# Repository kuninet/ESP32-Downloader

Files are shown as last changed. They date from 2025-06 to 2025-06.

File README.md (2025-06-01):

# ESP32/ESP8266 Downloader基板

## 概要
* ESP32/ESP8266 Downloader基板です。
* ピン配置は ESP32 Downloader kitに合わせています。
* MOS FET x2個で自動書き込み回路を装備してしています。
* USBシリアルICはCH340Kを使用しています。

## 回路図
[回路図](image/ESP32-Downloder.pdf)

## イメージ
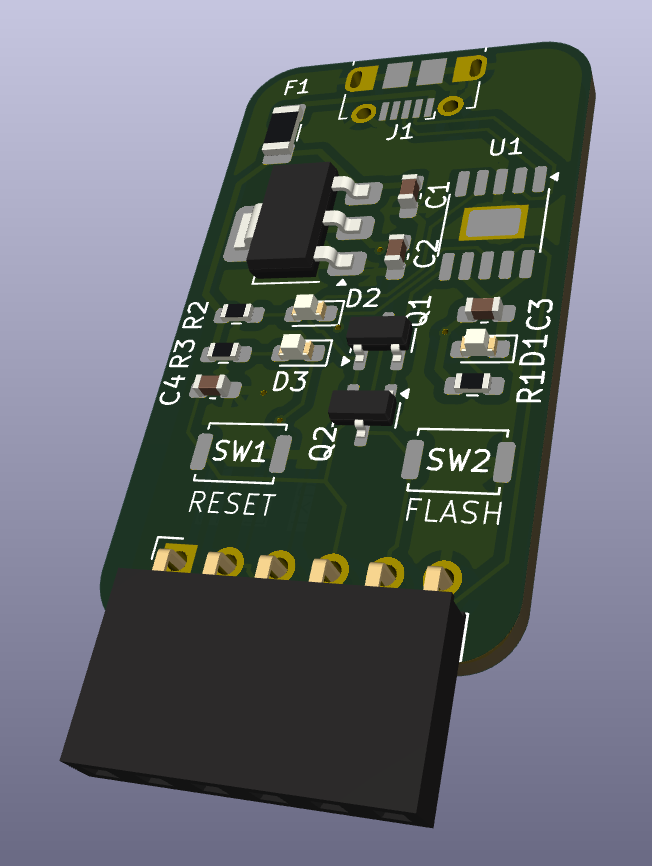
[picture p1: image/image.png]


## 参考
* ESP32 Downloader kit
  * https://docs.m5stack.com/ja/accessory/esp32_downloader_kit

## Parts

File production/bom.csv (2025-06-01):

Designator | Footprint | Quantity | Value | LCSC Part #
C1, C2 | 0603 | 2 | 22u
C3 | 0603 | 1 | 1u
C4 | 0603 | 1 | 0.1u
D1 | 0603 | 1 | LED_POWER
D2 | 0603 | 1 | LED_TXT
D3 | 0603 | 1 | LED_RXD
F1 | 1206 | 1 | Polyfuse
J1 | USB_Micro-B_Molex-105017-0001 | 1 | USB_B_Micro
J2 | PinSocket_1x06_P2.54mm_Horizontal | 1 | ESP32_DOWNLOAD_CON
Q1, Q2 | SOT-23 | 2 | BSS138
R1, R2, R3 | 0603 | 3 | 1k
SW1 | SW_Push_SPST_NO_Alps_SKRK | 1 | RESET
SW2 | SW_Push_SPST_NO_Alps_SKRK | 1 | FLASH
U1 | SSOP-10-1EP_3.9x4.9mm_P1mm_EP2.1x3.3mm | 1 | CH340K
U2 | SOT-223-3_TabPin2 | 1 | AMS1117-3.3

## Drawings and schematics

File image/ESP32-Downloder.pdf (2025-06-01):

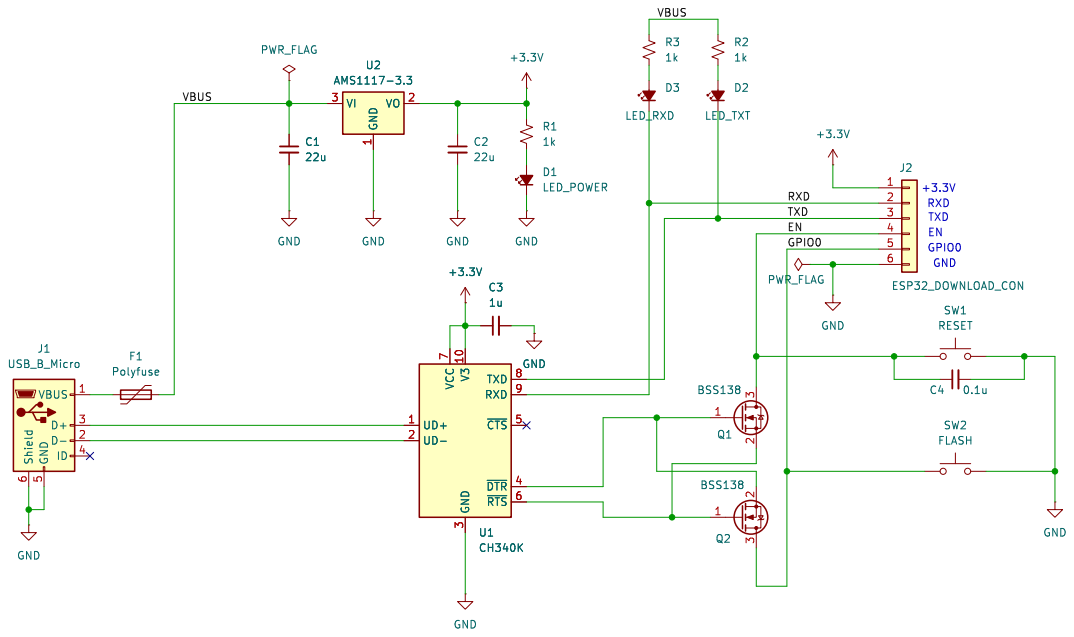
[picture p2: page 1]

3 TXD 8 RXD 9 ~{CTS}5 ~{DTR}4 ~{RTS}6 U1 CH340K C4 0.1u GND GND

3 TXD 8 RXD 9 ~{CTS}5 ~{DTR}4 ~{RTS}6 +3.3V GND

File: ESP32-Downloder.kicad_sch Sheet: / KUNI-NET

Id: 1/1 Title: ESP32 Downloader Board

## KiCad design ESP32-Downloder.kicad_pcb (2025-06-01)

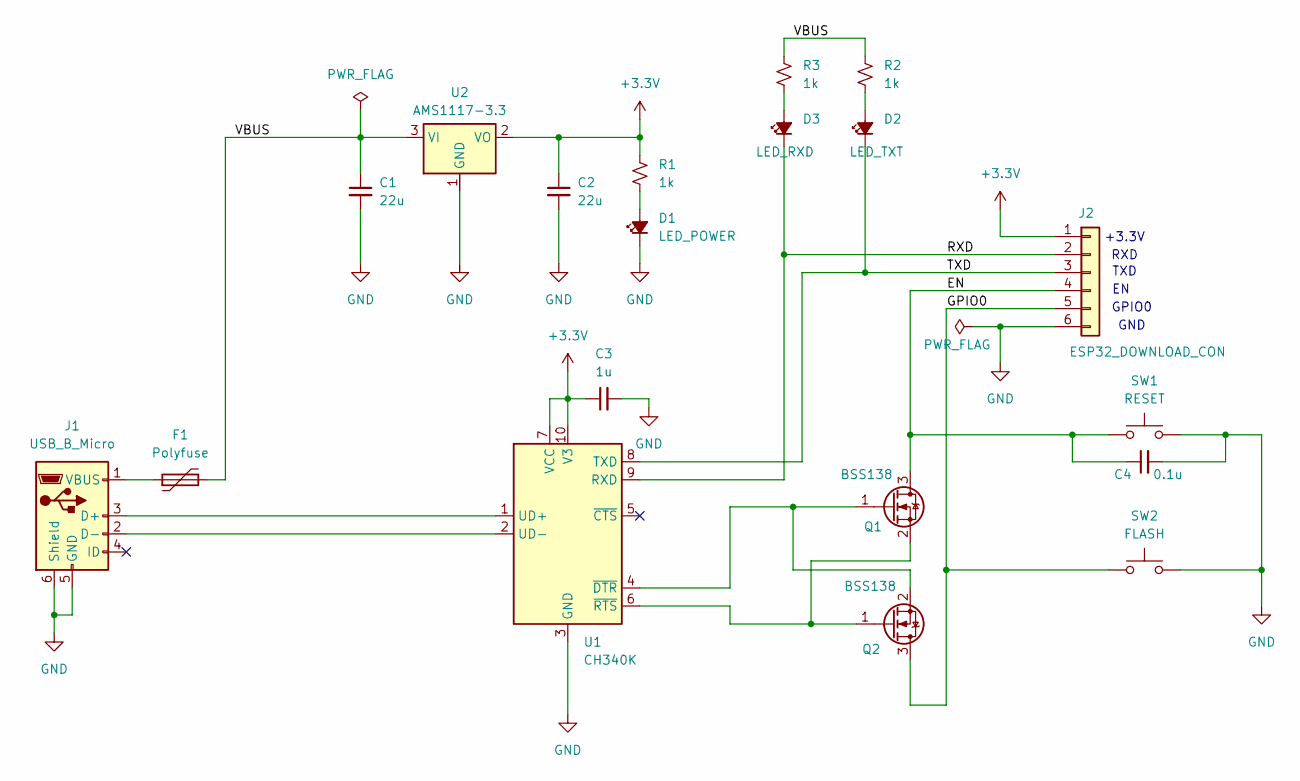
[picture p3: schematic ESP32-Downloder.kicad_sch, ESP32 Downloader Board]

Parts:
C1, C2: 22u; C_0603_1608Metric_Pad1.08x0.95mm_HandSolder
C3: 1u; C_0603_1608Metric_Pad1.08x0.95mm_HandSolder
C4: 0.1u; C_0603_1608Metric_Pad1.08x0.95mm_HandSolder
D1: LED_POWER; LED_0603_1608Metric_Pad1.05x0.95mm_HandSolder
D2: LED_TXT; LED_0603_1608Metric_Pad1.05x0.95mm_HandSolder
D3: LED_RXD; LED_0603_1608Metric_Pad1.05x0.95mm_HandSolder
F1: Polyfuse; Fuse_1206_3216Metric_Pad1.42x1.75mm_HandSolder
J1: USB_B_Micro; USB_Micro-B_Molex-105017-0001
J2: ESP32_DOWNLOAD_CON; PinSocket_1x06_P2.54mm_Horizontal
Q1, Q2: BSS138; SOT-23
R1, R2, R3: 1k; R_0603_1608Metric_Pad0.98x0.95mm_HandSolder
SW1: RESET; SW_Push_SPST_NO_Alps_SKRK
SW2: FLASH; SW_Push_SPST_NO_Alps_SKRK
U1: CH340K; SSOP-10-1EP_3.9x4.9mm_P1mm_EP2.1x3.3mm
U2: AMS1117-3.3; SOT-223-3_TabPin2

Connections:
+3.3V: C2.1, C3.1, J2.1, R1.1, U1.7 (VCC), U1.10 (V3), U2.2 (VO)
/EN: C4.1, J2.4, Q1.3 (D), SW1.1
/GPIO0: J2.5, Q2.3 (D), SW2.1
/RXD: D3.1 (K), J2.2, U1.9 (RXD)
/TXD: D2.1 (K), J2.3, U1.8 (TXD)
/VBUS: C1.1, F1.2, R2.1, R3.1, U2.3 (VI)
GND: C1.2, C2.2, C3.2, C4.2, D1.1 (K), J1.5 (GND), J1.6 (Shield), J2.6, SW1.2, SW2.2, U1.3 (GND), U1.11 (GND), U2.1 (GND)
unnamed: D1.2 (A), R1.2
unnamed: D2.2 (A), R2.2
unnamed: D3.2 (A), R3.2
unnamed: J1.3 (D+), U1.1 (UD+)
unnamed: J1.2 (D-), U1.2 (UD-)
unnamed: F1.1, J1.1 (VBUS)
unnamed: Q1.1 (G), Q2.2 (S), U1.4 (~DTR)
unnamed: Q1.2 (S), Q2.1 (G), U1.6 (~RTS)

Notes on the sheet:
GND
TXD
+3.3V
GPIO0
RXD

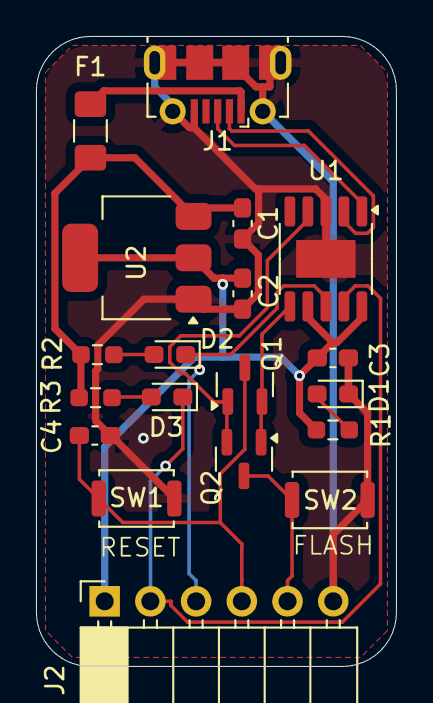
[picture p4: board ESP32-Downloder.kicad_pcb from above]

Board: 2 copper layers, 20.0 x 35.0 mm, 19 parts (0 on the bottom side), 15 nets.

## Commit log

2025-06-01 README追加、ガーバーデータ出力
    [ESP32-Downloder.dsn, ESP32-Downloder.kicad_pcb, ESP32-Downloder.kicad_sch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]
2025-06-01 3Dイメージ追加
